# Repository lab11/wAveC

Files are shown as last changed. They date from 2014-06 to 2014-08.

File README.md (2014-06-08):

wAveC - View AC Current and Voltage Waveforms
=============================================

Often it is useful to simultaneously view the current and voltage waveforms
for a load. Breaking out the high-voltage phase line for attaching an
oscilloscope can be precarious. This device is a simple way to plug in
a load and run BNC cables to a scope to see a real-time view of the
waveforms.

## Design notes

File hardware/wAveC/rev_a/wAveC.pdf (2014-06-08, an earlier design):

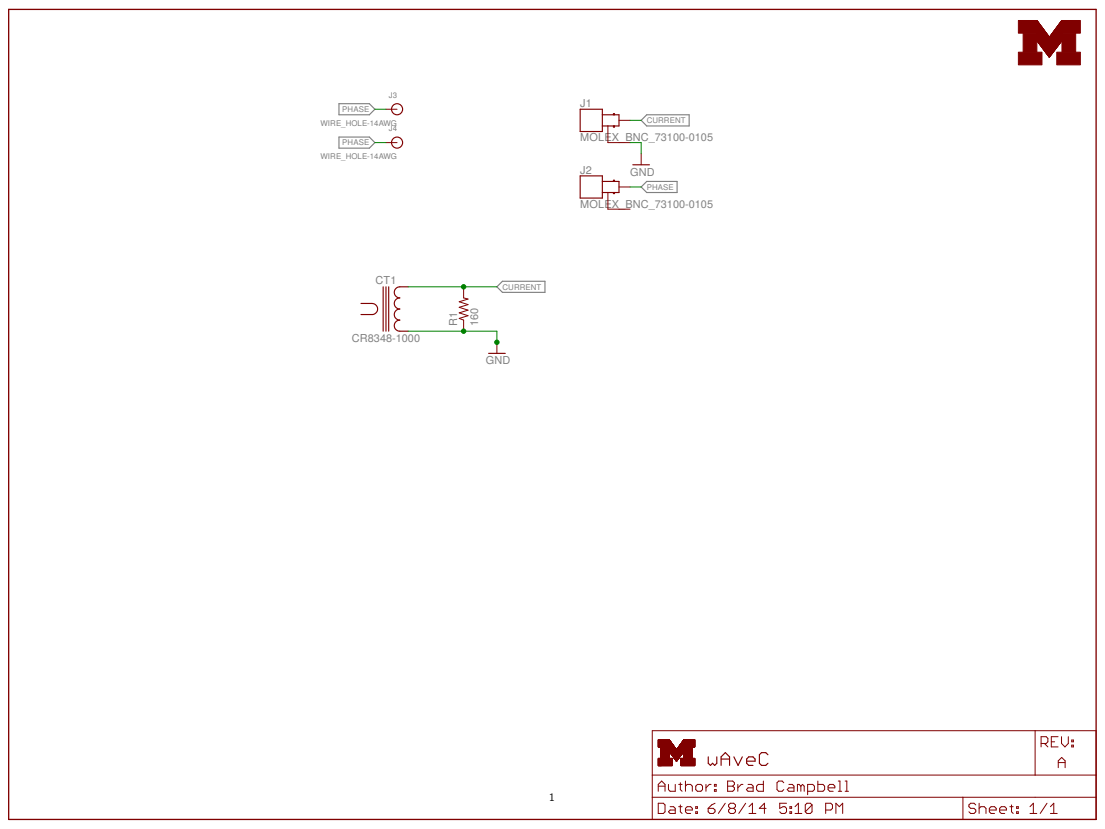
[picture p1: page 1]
160 GND; WIRE_HOLE-14AWG WIRE_HOLE-14AWG; MOLEX_BNC_73100-0105; GND; CURRENT; CURRENT PHASE; PHASE

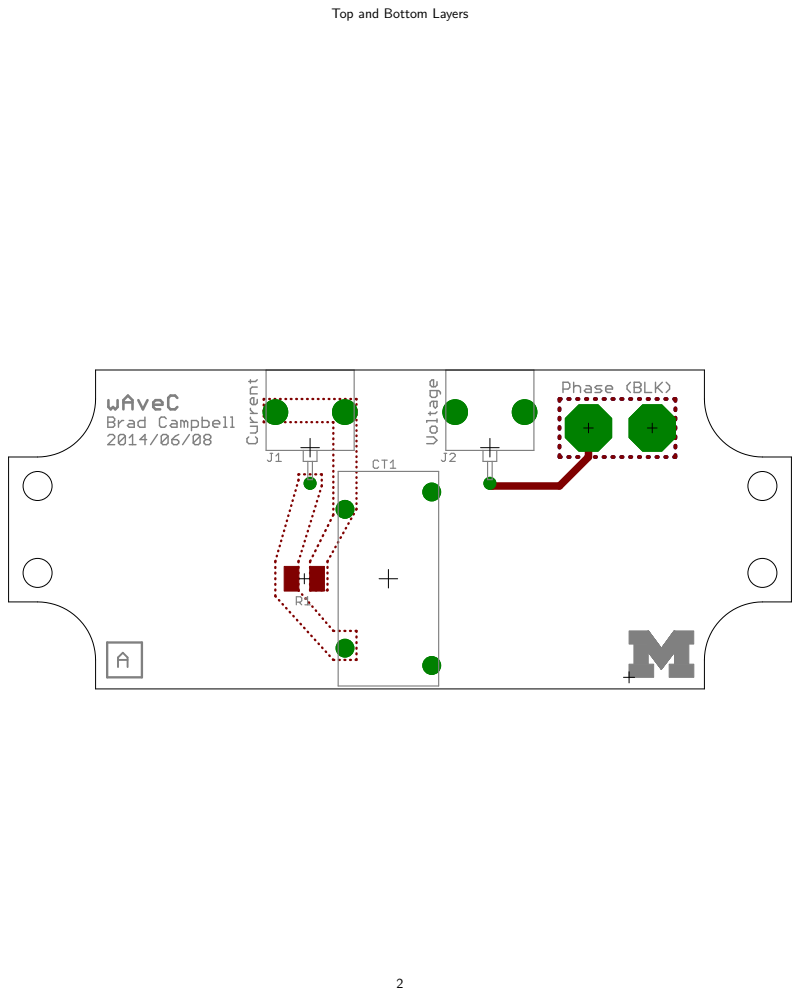
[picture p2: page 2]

Top and Bottom Layers

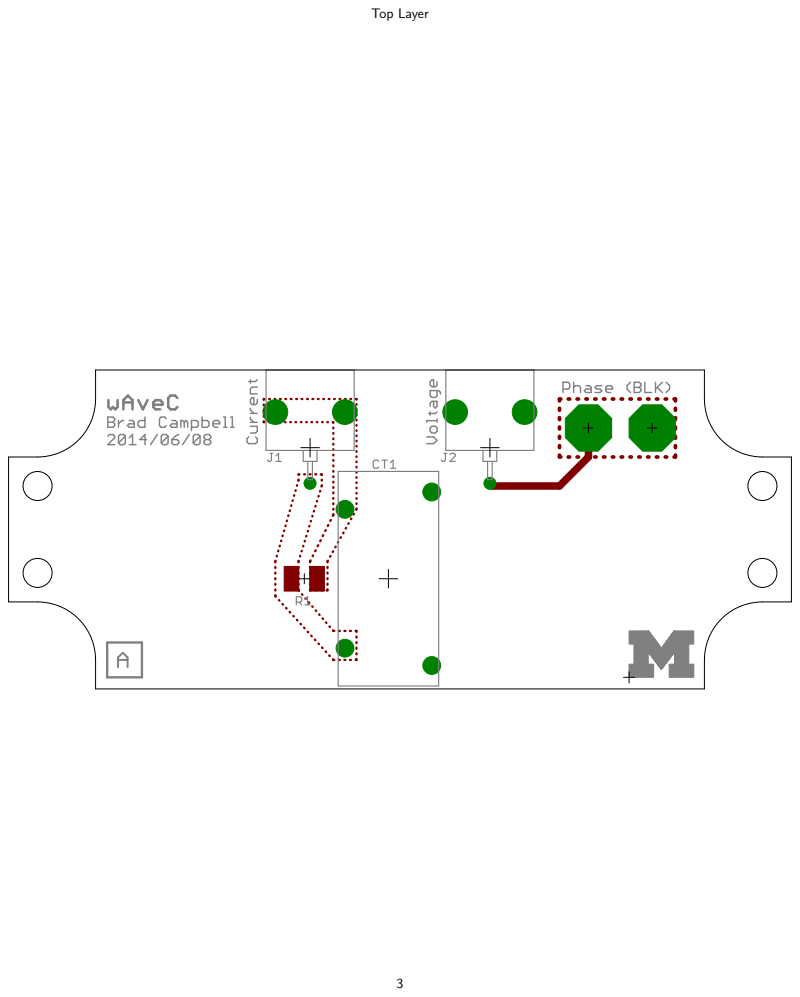
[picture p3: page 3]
Top Layer

Bottom Layer

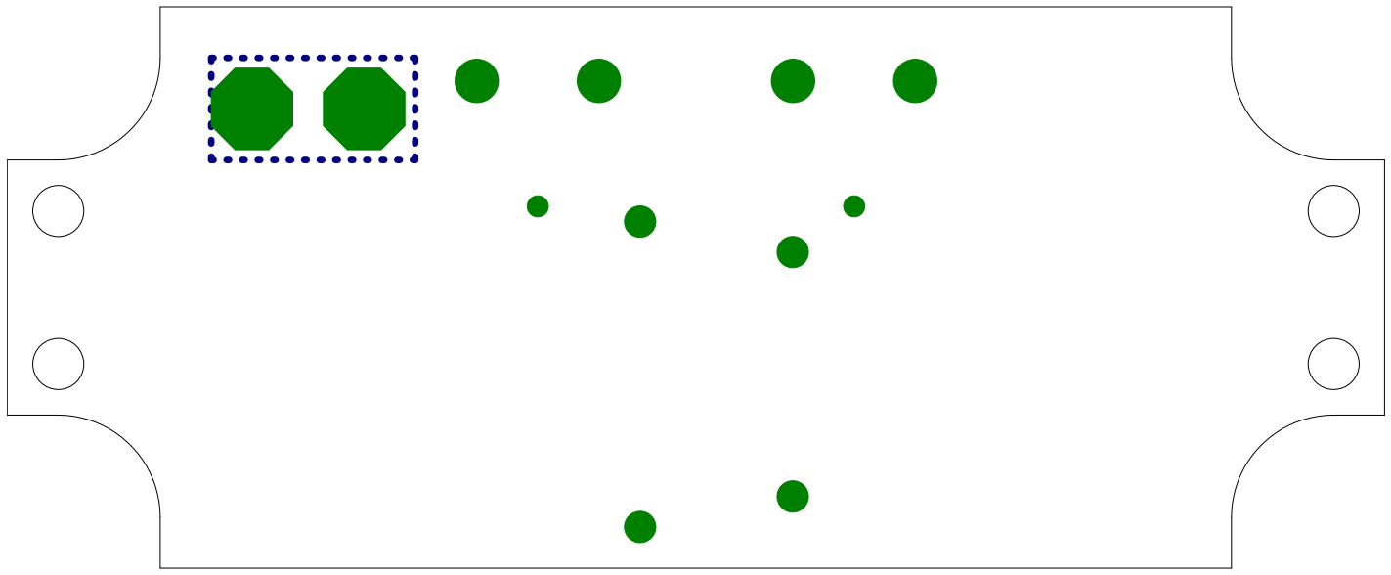
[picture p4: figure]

Top Copper Layer

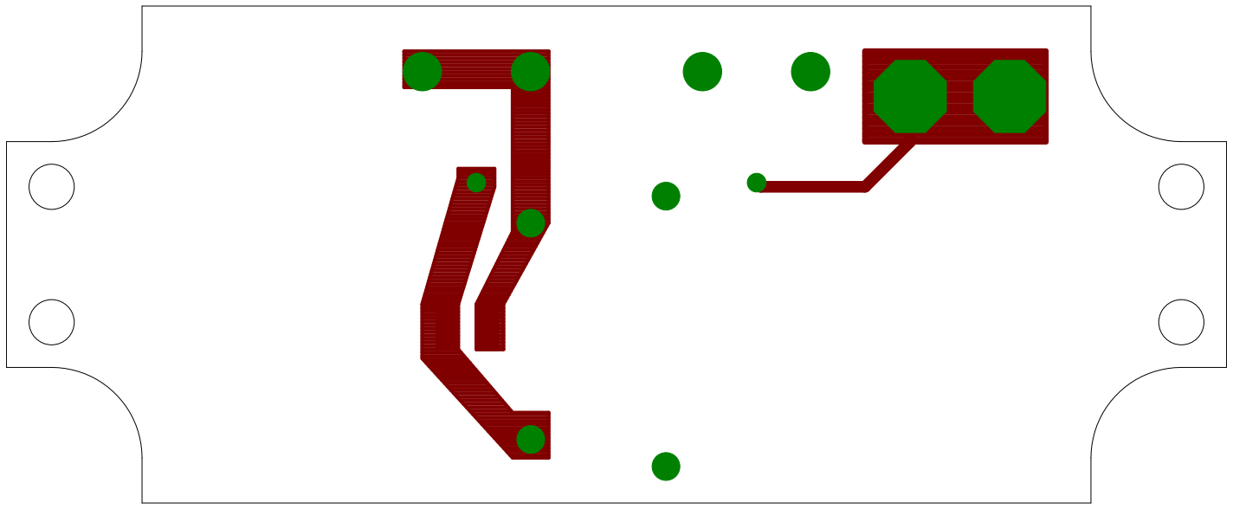
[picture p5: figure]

Bottom Copper Layer

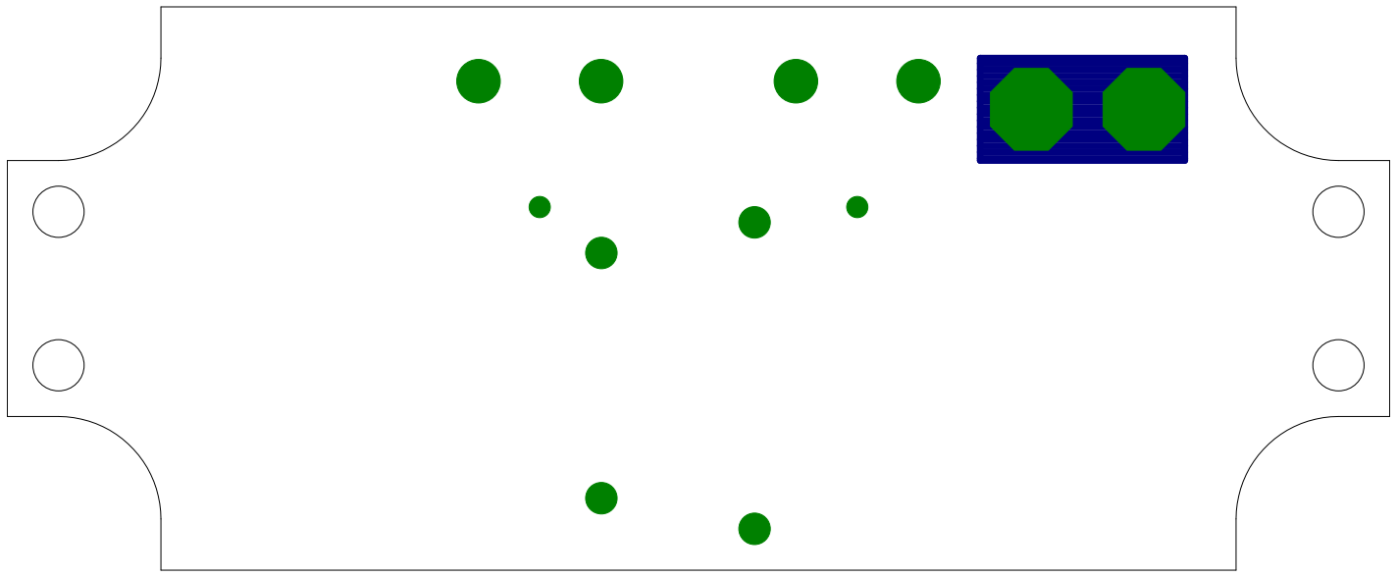
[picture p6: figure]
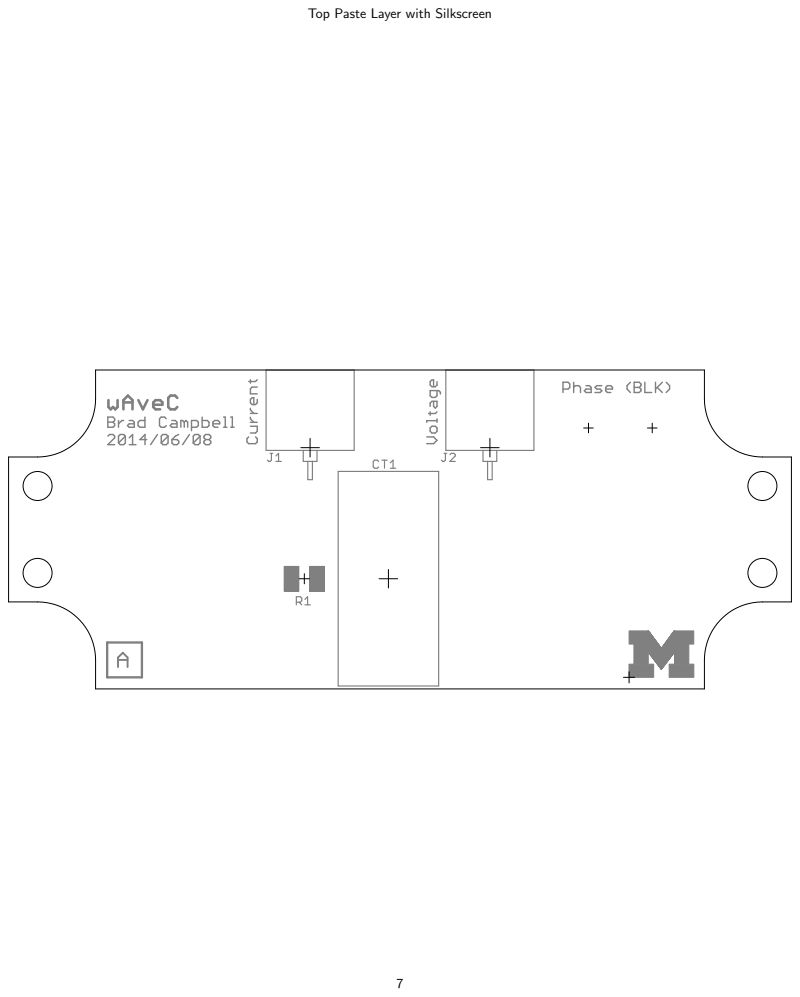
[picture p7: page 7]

Top Paste Layer with Silkscreen

Bottom Paste Layer with Silkscreen

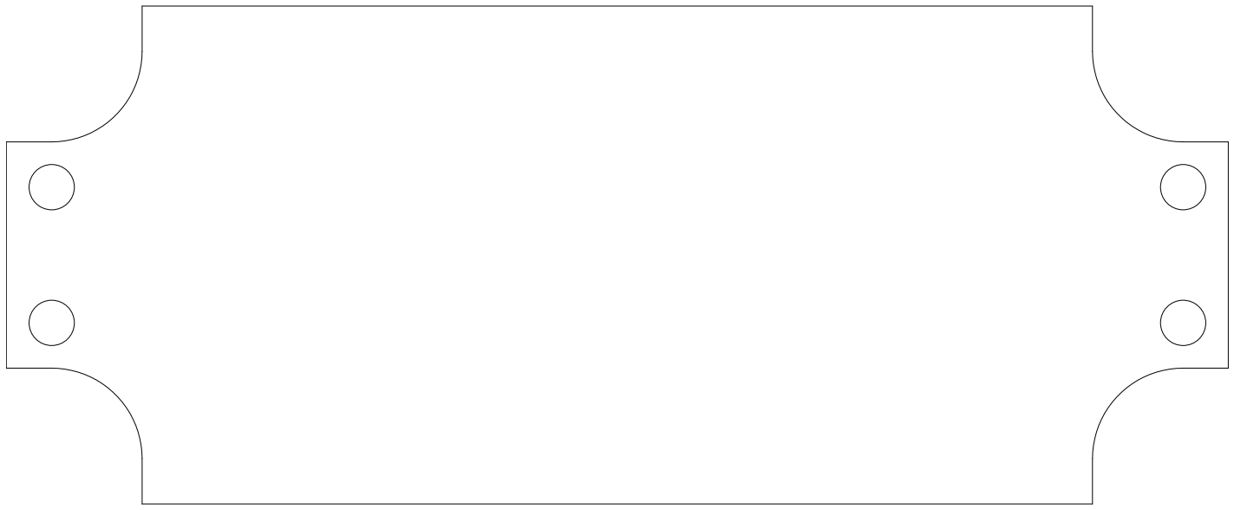
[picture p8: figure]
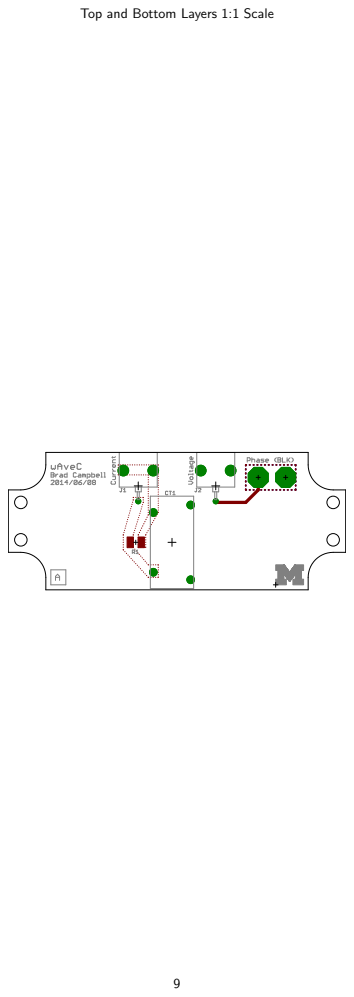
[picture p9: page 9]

Top and Bottom Layers 1:1 Scale

Top Layer 1:1 Scale

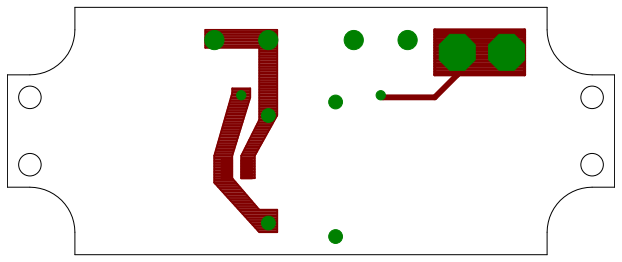
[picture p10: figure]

Bottom Copper Layer 1:1 Scale

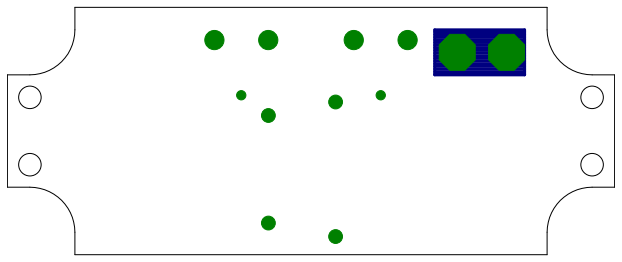
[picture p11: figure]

### Sheet1

Qty Value | Device | Package | Parts
1 CR8348-1000 | CR8348-1000 | CR8348 | CT1
2 MOLEX_BNC_73100-0105 MOLEX_BNC_73100-0105 MOLEX-BNC-73100-0105 J1, J2
1 160 | R-US_R1210 | R1210 | R1

### Sheet1

Description | DIGIKEY
Current Transformer General Purpose 582-1161-ND CONN BNC JACK R/A 50 OHM PCB WM5524-ND
RESISTOR, American symbol | P160QCT-ND

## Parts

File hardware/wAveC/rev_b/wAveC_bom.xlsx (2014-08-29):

Qty | Value | Device | Package | Parts | Description | DIGIKEY
1 | CR8348-1000 | CR8348-1000 | CR8348 | CT1 | Current Transformer General Purpose | 582-1161-ND
2 | MOLEX_BNC_73100-0105 | MOLEX_BNC_73100-0105 | MOLEX-BNC-73100-0105 | J1, J2 | CONN BNC JACK R/A 50 OHM PCB | WM5524-ND
1 | 160 | R-US_R1210 | R1210 | R1 | RESISTOR, American symbol | P160QCT-ND
1 | 9.1M | RESISTOR1206 | R1206 | R2 | RESISTOR, American symbol | 311-9.10MFRCT-ND

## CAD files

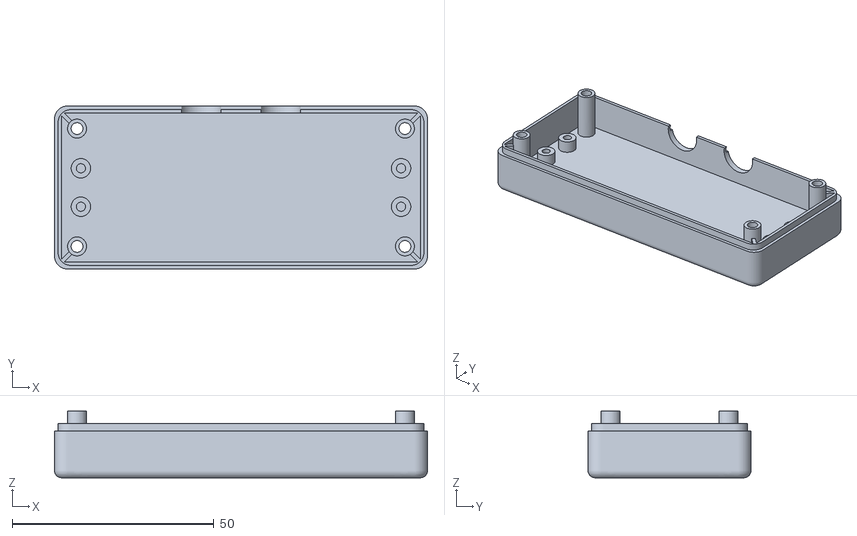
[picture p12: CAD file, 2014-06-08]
case/case_bottom.stl
92.5 x 40.4 x 16.5

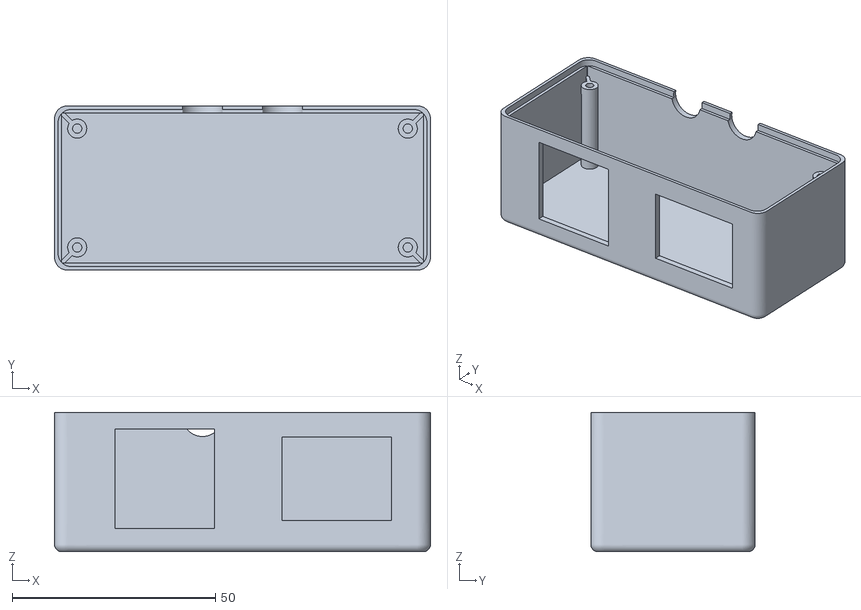
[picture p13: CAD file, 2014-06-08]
case/case_top.stl
92.5 x 40.4 x 34.3

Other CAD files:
case/0731000105.ipt
case/701W-X202.ipt
case/739W-X203.ipt
case/assembly.iam
case/case_bottom.ipt
case/case_top.ipt
case/cr8348-1000.ipt
case/pcb.ipt

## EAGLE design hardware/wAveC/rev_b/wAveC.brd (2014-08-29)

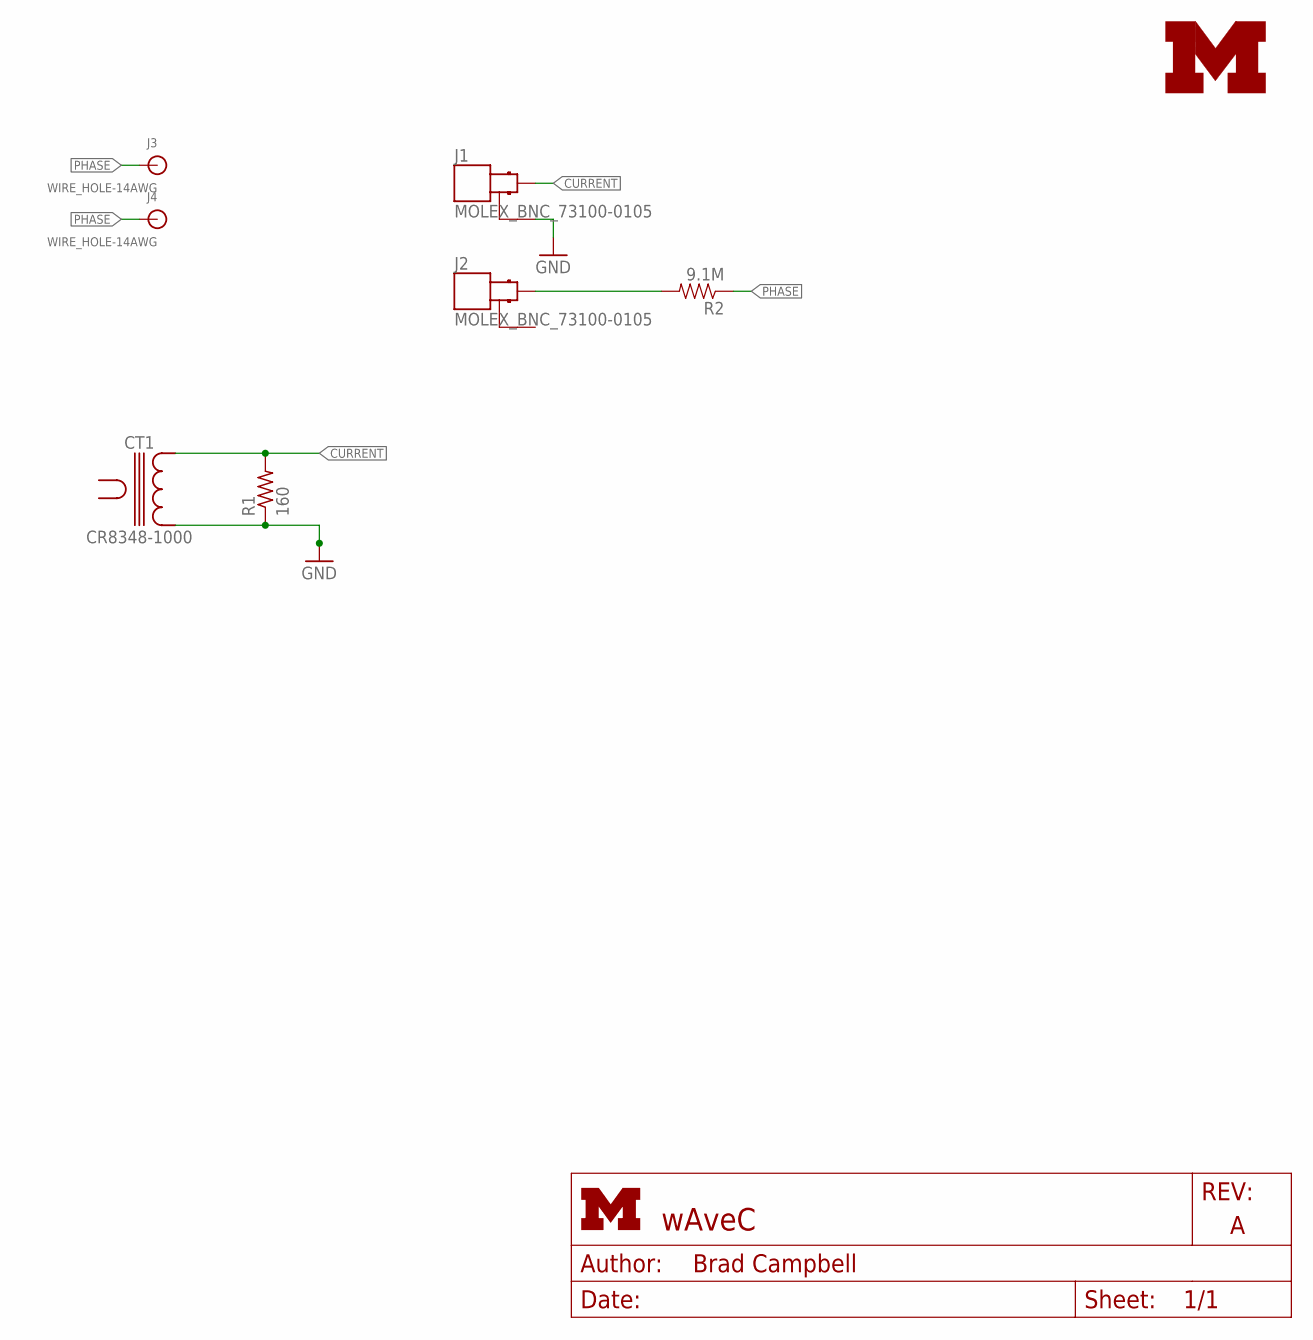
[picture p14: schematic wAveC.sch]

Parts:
CT1: CR8348-1000; CR8348
J1, J2: MOLEX_BNC_73100-0105; MOLEX-BNC-73100-0105
J3, J4: WIRE_HOLE-14AWG
LOGO1: UMICH_SOLID_MEDIUM; UMICH_SOLID_200MIL
R1: 160; R1210; DIGIKEY P160QCT-ND
R2: 9.1M; 1206; DIGIKEY 311-9.10MFRCT-ND

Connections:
CURRENT: CT1.1, J1.SIGNAL, R1.2
GND: CT1.2, J1.GND1 (GND), J1.GND2 (GND), R1.1
unnamed: J2.SIGNAL, R2.2
PHASE: J3.P$1, J4.P$1, R2.1

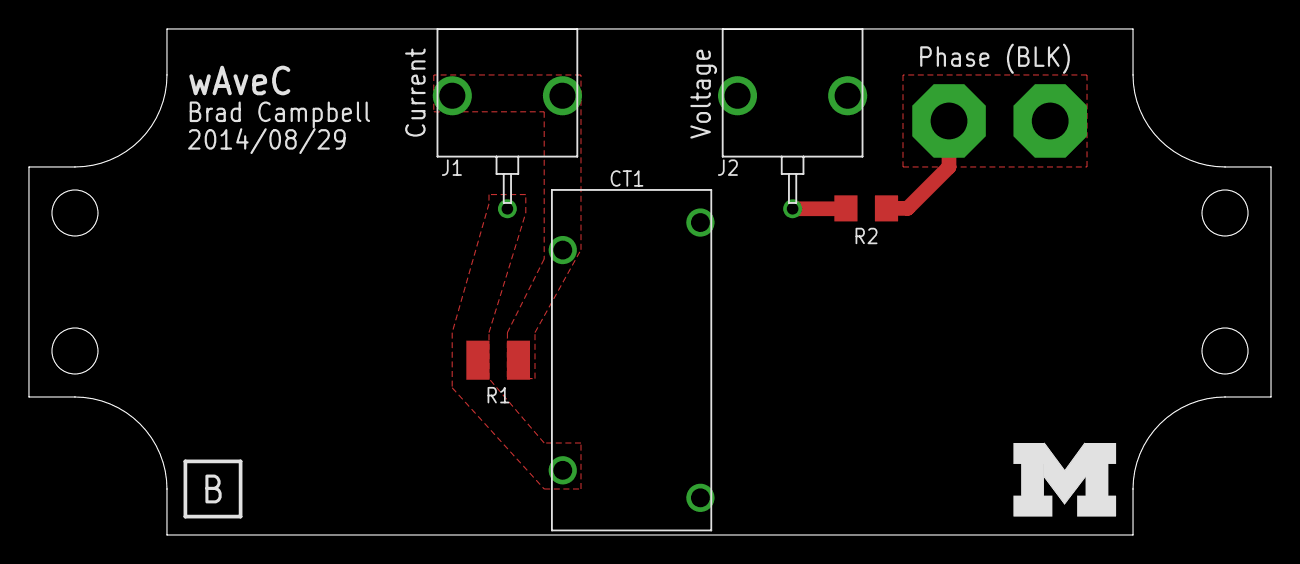
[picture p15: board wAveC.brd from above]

Board: 2 copper layers, 85.7 x 34.9 mm, 8 parts (0 on the bottom side), 4 nets.

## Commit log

2014-05-18 adding wavec schematic
    [wAveC.sch]
2014-05-18 added some layout
    [wAveC.brd, wAveC.sch]
2014-05-18 wavec routed
    [wAveC.brd, wAveC.sch]
2014-05-19 added silkscreen
    [wAveC.brd, wAveC.sch]
2014-06-08 first pass at bottom of case
    created a case bottom and all the pcb parts in cad
    [0731000105.0003.ipt, 0731000105.ipt, 701W-X202.ipt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]
2014-06-08 added top to case
    made walls skinnier too
    [0731000105.ipt, 701W-X202.ipt, 739W-X203.ipt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]
2014-06-08 updated wavec labels and date
    [wAveC.brd, wAveC.sch]
2014-06-08 bom + files to ship
    [wAveC_bom.csv, wAveC_bom.xlsx]
2014-08-29 wave c with 9 megaohm resistor
    [wAveC.brd, wAveC.sch, wAveC_bom.xlsx]

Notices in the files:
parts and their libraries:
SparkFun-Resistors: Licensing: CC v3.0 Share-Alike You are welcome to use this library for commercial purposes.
